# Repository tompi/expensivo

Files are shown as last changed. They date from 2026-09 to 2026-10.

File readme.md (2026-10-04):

Expensivo
=========

A wireless version of the [Cheapino](https://github.com/tompi/cheapino): same
shape and key layout, but with a nice!nano in each half, ZMK and Bluetooth
between the halves. Not quite as cheap anymore, hence the name.

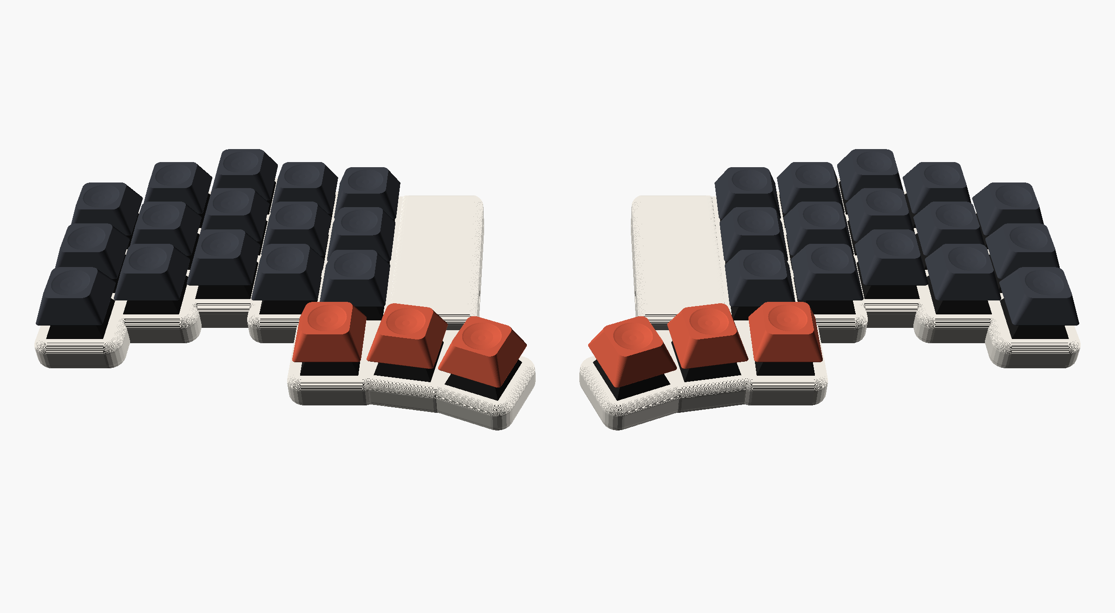
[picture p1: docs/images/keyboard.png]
Expensivo, both halves


- 36 keys (3x5 + 3 thumb keys per half), MX hotswap sockets
- every key has its own pin on the nice!nano: no diodes, no matrix
- one reversible PCB for both halves: the left half is built on the front,
  the right half on the back
- LiPo battery, power switch and reset button on each half
- optional EC11 encoder on the right half
- 3D-printed case with an optional magnetic cover over the nice!nano

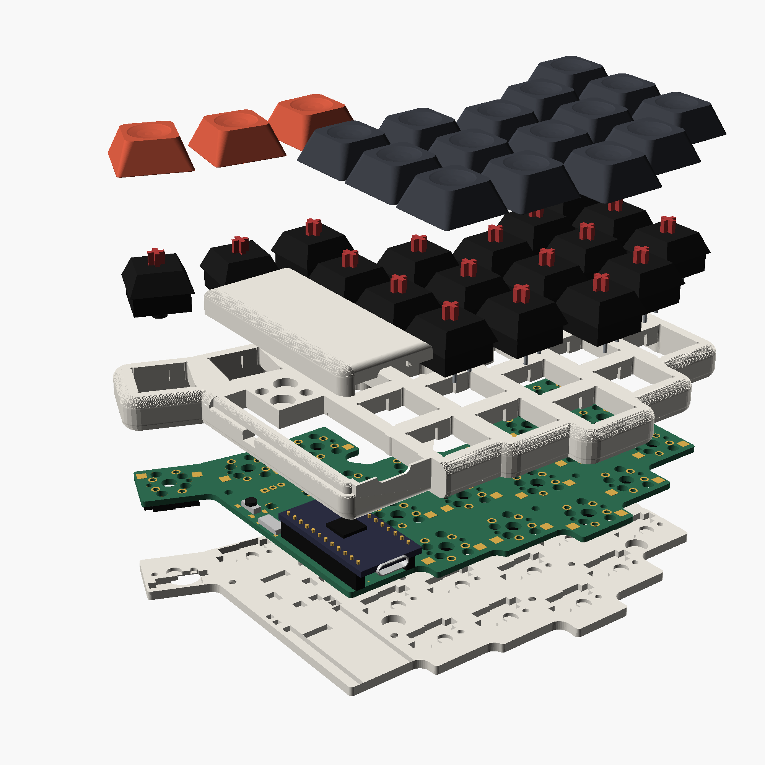
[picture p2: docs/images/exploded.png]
Exploded view: keycaps, switches, top case and cover, PCB with nice!nano, bottom plate


Parts per keyboard
------------------

| Part | Qty | Notes |
|---|----:|---|
| PCB | 2 | same board for both halves, see [Ordering the PCB](#ordering-the-pcb) |
| nice!nano v2 | 2 | or a compatible nRF52840 Pro Micro clone |
| Sockets + pins for the nice!nano | 2 sets | 12-pin single row; the case assumes the nano sits 4.9 mm above the PCB |
| LiPo battery | 2 | fits under the nano between the sockets, e.g. 301230 (3 x 12 x 30 mm); may stick out ~6 mm past the nano |
| MX switches | 36 | |
| Kailh MX hotswap sockets | 36 | MX, not low profile |
| Slide switch PCM12SMTR | 2 | one per half |
| Tactile switch TL3342 | 2 | reset, one per half |
| Keycaps | 36 | |
| EC11 encoder | 0-1 | optional, right half only |

For the case, per keyboard: 16 M2 heat-set inserts (4 mm long, 3 mm OD),
16 M2x5 countersunk screws, silicone bumpers (10 mm), 8 + 8 6x2 mm magnets
(8 in the bottom plates, 8 for the two covers).

Building it
-----------

The PCB is reversible, so it matters which side you solder on:

- **left half:** everything on the front side (the side marked LEFT);
  hotswap sockets on the back
- **right half:** everything on the back side (marked RIGHT); hotswap sockets on the front
- the nice!nano goes on the same side as its label, components facing up
- bridge the four solder jumpers next to the nano's top pins on the side the
  nano is on (marked "BRIDGE ALL 4"), and leave the other four open
- the power switch and reset button have a footprint on each side; fit only
  the one on top
- battery to the pads below the nano, + and - are marked

The [schematic](pcb/expensivo.kicad_sch) shows how it is wired, including
which nano pin ends up on which hole on each side.

Firmware
--------

ZMK, built by GitHub Actions on every push (see the Actions tab for the
`.uf2` files). The left half is the central and has ZMK Studio enabled.

- keymap: [config/expensivo.keymap](config/expensivo.keymap)
- shield: [zmk/boards/shields/expensivo](zmk/boards/shields/expensivo)

To flash, double-tap reset and copy the matching `.uf2` to the drive that
shows up. Flash `settings_reset` first if the nanos were used before.

Case
----

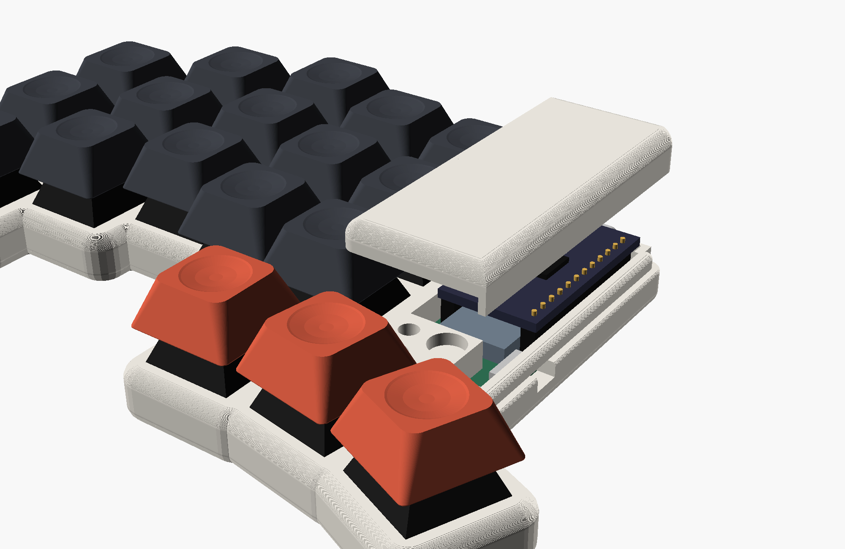
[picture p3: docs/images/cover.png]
Cover lifted off, showing the magnets and locating pegs


OpenSCAD files in [case/](case), see [case/readme.md](case/readme.md). The
top frames print top face down without supports, so do the covers; the
covers hold on with magnets and can be left off.

Ordering the PCB
----------------

`scripts/gerbers.sh` writes `build/expensivo-jlcpcb.zip`, ready for JLCPCB:
2 layers, 1.6 mm, default settings. 5 boards is two keyboards and a spare.
Choose ENIG if you want the copper logo to stay shiny.

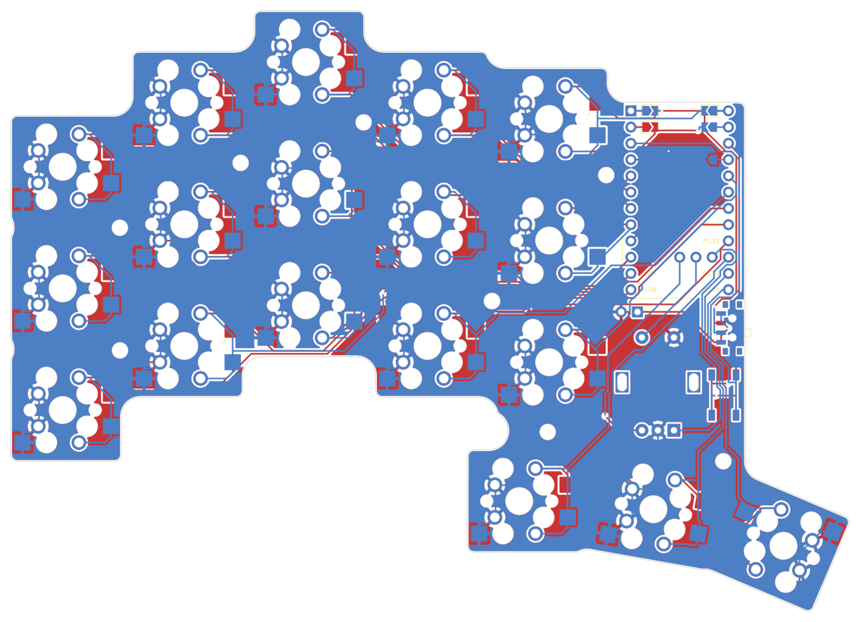
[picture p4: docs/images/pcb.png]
The PCB


How it's made
-------------

Everything is generated by scripts, so edit those rather than the outputs:

| Script | Makes |
|---|---|
| `scripts/build.sh` | the full board build: footprint, PCB, routing, DRC/ERC, schematic, case data |
| `scripts/build_pcb.py` | the PCB, starting from the Cheapino board: parts, nets, outline, logo |
| `scripts/gen_nano_footprint.py` | the reversible nice!nano footprint |
| `scripts/gen_schematic.py` | the schematic, from the PCB's parts and nets |
| `scripts/gen_zmk.py` | the ZMK shield pin lists |
| `scripts/gen_case.py` | PCB geometry for the OpenSCAD case |
| `scripts/gerbers.sh` | Gerbers and drill files for JLCPCB |

The pin map shared by the PCB, schematic and firmware is in
`scripts/layout.py`. Routing is done by Freerouting (downloaded on first run,
needs Java). The scripts expect KiCad 8 in `/Applications/KiCad`.

License
-------

This work is licensed under a [Creative Commons Attribution license.](LICENSE.txt)

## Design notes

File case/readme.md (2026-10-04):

3D-printed case
===============

Adapted from the cheapino case (`../cheapino/case`). Parts:

- `expensivo-top-left.scad`, `expensivo-top-right.scad`: top frames, flat on top
  like the cheapino case and flipped for printing (top face on the bed). The
  nice!nano sits in an open well.
- `expensivo-cover-left.scad`, `expensivo-cover-right.scad`: optional covers over
  the nice!nano (on 4.9 mm sockets), also printed top face down. Under the
  cover everything is open from the pcb to its roof (10 mm), so the battery
  can stick out past the nano's end. Each cover holds on with two 6x2 mm
  magnets glued into matching pockets in cover and top frame (check the
  polarity before the glue sets) and is located by two pegs; magnets and pegs
  share a small solid block at the thumb end.
- `expensivo-assembly.scad`: both halves put together, for looking at (F5)
- `expensivo-bottom-left.scad`, `expensivo-bottom-right.scad`: bottom plates

All board geometry (outline, keys, holes, parts) comes from `expensivo-pcb.scad`,
which `scripts/gen_case.py` generates from the PCB (`scripts/build.sh` runs it),
so the case follows PCB changes. Positions typed in by hand (bumpers, magnets)
are in KiCad coordinates, see `at()` in `modules.scad`.

Compared to the cheapino case: no RJ45 or diode cutouts; both halves get a
nice!nano well, a snug USB-C opening in a flat end face (lower half in the top
frame, upper half in the cover), a slot for the power switch lever and
room for the reset button (take the cover off to press it). The battery sits under the nice!nano,
between the socket rows, and may stick out about 6 mm past its end. The nano's stack (socket height, parts, mid-mount USB-C position and size,
clearances) is set in the "cover over the nice!nano" part of `modules.scad`.
To fit the encoder after all, pass `encoder=true` in `expensivo-top-right.scad`;
the cover's magnets use that spot, so that half then goes without a cover.

Render with a recent OpenSCAD snapshot with the manifold backend enabled, e.g.

    openscad --enable=manifold -o top-left.stl expensivo-top-left.scad

The USB-C numbers are measured on the nice!nano v2 model and match the common
33 x 17.78 mm clones; check them against your board (height of the shell
above the PCB, and how far it sticks out past the nano's edge) before printing.
The end wall beside the port is only as thick as that overhang (0.74 mm).

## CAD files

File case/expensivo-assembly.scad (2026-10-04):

// Visual assembly of both halves: case, pcb, nice!nano, switches and keycaps.
// For looking at only (F5); the case parts are imported from the STLs in
// build/case (in print orientation), so render those parts to STL first.
// explode > 0 spreads the layers apart vertically to show what is inside.
$fn = 34;
step = 0.5;
include <modules.scad>

explode = 0;
show_top = true;      // false to see inside
show_cover = true;
cover_lift = 0;       // lift the cover off to show the magnets and pegs
show_caps = true;
show_right = true;
half_gap = 150;       // distance between the two halves' centres

pcb_color = "#2d6a4f";
copper_color = "#d4a84b";
case_color = "#e9e5dc";
cover_color = "#e9e5dc";
cap_color = "#3a3d44";
cap_accent = "#c8553d";

// height of each layer when exploded
function lift(layer) = explode * layer;
L_PCB = 1;      // pcb, sockets, nano
L_TOP = 2;      // top frame
L_SWITCH = 3;   // switches
L_COVER = 3;    // cover (beside the switches)
L_CAP = 4;      // keycaps

module pcb_pad_shape(p) {
    translate([p[0], p[1]]) rotate(p[4])
        if (p[5] == 1) resize([p[2], p[3]]) circle(d=1);
        else square([p[2], p[3]], center=true);
}

// board with its drill holes, and the copper pads on the top side
module pcb() {
    translate([0, 0, bottom_plate_thickness]) {
        color(pcb_color) linear_extrude(pcb_thickness) difference() {
            base();
            for (p = pads_front) if (p[6] > 0) translate([p[0], p[1]]) circle(d=p[6]);
        }
        color(copper_color) translate([0, 0, pcb_thickness]) linear_extrude(0.05)
            difference() {
                for (p = pads_front) pcb_pad_shape(p);
                for (p = pads_front) if (p[6] > 0) translate([p[0], p[1]]) circle(d=p[6]);
            }
    }
}

// hotswap sockets under the board (the left half has them on the back)
module sockets(bottom) {
    color("#1b1b1b")
    for (k = keys)
        translate([k[0], k[1], bottom_plate_thickness - 1.85]) rotate(k[2]) translate([0.57, 4.7, 0])
            translate([0, bottom ? -9.42 : 0, 0]) mirror([0, bottom ? 0 : 1, 0])
                linear_extrude(1.85) projection() hotswap_mx();
}

// Cherry MX style switch, its bottom resting on the pcb
module mx_switch() {
    color("#9aa0a6") for (p = [[-3.81, 2.54], [2.54, 5.08]]) translate([p[0], p[1], top_of_pcb - 3.3])
        cylinder(h=3.3, d=1);
    color("#1b1b1b") translate([0, 0, top_of_pcb - 3.3]) cylinder(h=3.3, d=3.8);
    color("#1b1b1b") translate([0, 0, top_of_pcb])
        linear_extrude(case_top - top_of_pcb) square(14, center=true);
    color("#1b1b1b") hull() {
        translate([0, 0, case_top]) linear_extrude(0.1) square(15.6, center=true);
        translate([0, 0, case_top + 5.2]) linear_extrude(0.1) square(11, center=true);
    }
    color("#b33a3a") translate([0, 0, case_top + 5.2]) linear_extrude(3.4) {
        square([4, 1.2], center=true);
        square([1.2, 4], center=true);
    }
}

// DSA-like keycap: straight tapered sides and a slightly dished top.
module keycap(accent=false) {
    color(accent ? cap_accent : cap_color) difference() {
        hull() {
            linear_extrude(0.1) offset(r=1) square(18.2 - 2, center=true);
            translate([0, 0, 7.4]) linear_extrude(0.1) offset(r=2) square(12.7 - 4, center=true);
        }
        translate([0, 0, 7.4 + 20 - 0.6]) sphere(r=20, $fn=64);
    }
}

// nice!nano on its sockets, with the battery between the socket rows
module mcu() {
    nano_w = nano[2] - nano[0];
    nano_l = nano[3] - nano[1];
    pin_x = [nano[0] + 1.62, nano[2] - 1.62];
    // sockets
    color("#111111") for (x = pin_x)
        translate([x - 1.27, nano[1] + 0.4, top_of_pcb]) cube([2.54, 30.5, socket_height]);
    // battery
    // sticking out past the nano's end, into the space under the cover
    color("#6c7a89") translate([nano_x - 6, nano[1] - 4, top_of_pcb]) cube([12, 30, 3]);
    translate([0, 0, top_of_pcb + socket_height]) {
        color("#2b2d42") translate([nano[0], nano[1], 0]) cube([nano_w, nano_l, nano_thickness]);
        // pins through the nano
        color(copper_color) for (x = pin_x, i = [0:11])
            translate([x, nano[3] - 3.2 - i * 2.54, 0]) cylinder(h=nano_thickness + 0.8, d=0.8);
        // controller
        color("#111111") translate([nano_x - 3.5, nano[1] + 12, nano_thickness]) cube([7, 7, 0.9]);
    }
    // mid-mount USB-C receptacle, through the nano's board
    color("#c0c0c0") difference() {
        translate([nano_x, usb_mouth - usb_depth, usb_zc]) rotate([-90, 0, 0]) linear_extrude(usb_depth)
            hull() for (dx = [-1, 1]) translate([dx * (usb_width - usb_height) / 2, 0]) circle(d=usb_height);
        translate([nano_x, usb_mouth - 6.5, usb_zc]) rotate([-90, 0, 0]) linear_extrude(7)
            hull() for (dx = [-1, 1]) translate([dx * (usb_width - usb_height) / 2, 0]) circle(d=usb_height - 0.6);
    }
}

// small parts on the pcb: power switch, reset button
module small_parts() {
    color("#c0c0c0") translate([0, 0, top_of_pcb]) box(power_switch, 1.4, -0.4);
    color("#c0c0c0") translate([0, 0, top_of_pcb]) box(reset_button, 1.5, -1.3);
    color("#1b1b1b") translate([(reset_button[0] + reset_button[2]) / 2,
                               (reset_button[1] + reset_button[3]) / 2, top_of_pcb + 1.5])
        cylinder(h=1, d=3);
}

module switches_and_caps() {
    for (k = keys) translate([k[0], k[1], 0]) rotate(k[2]) {
        translate([0, 0, lift(L_SWITCH) - lift(L_PCB)]) mx_switch();
        if (show_caps) translate([0, 0, case_top + 6.3 + lift(L_CAP) - lift(L_PCB)])
            keycap(accent = k[1] < -25);   // thumb keys in the accent colour
    }
}

// the insides of one half, in the front view frame
module insides(left) {
    translate([0, 0, lift(L_PCB)]) {
        pcb();
        sockets(left);
        mcu();
        small_parts();
        switches_and_caps();
    }
}

// bottom plate, top case and cover from their STLs; the bottom plate is printed
// the way it sits, the others are turned back from their print orientation
module top_parts(side) {
    color(case_color) import(str("../build/case/expensivo-bottom-", side, ".stl"));
    if (show_top) color(case_color) translate([0, 0, lift(L_TOP)])
        rotate([0, 180, 0]) translate([0, 0, -case_top])
            import(str("../build/case/expensivo-top-", side, ".stl"));
    if (show_top && show_cover) color(cover_color) translate([0, 0, lift(L_COVER) + cover_lift])
        rotate([0, 180, 0]) translate([0, 0, -hump_top])
            import(str("../build/case/expensivo-cover-", side, ".stl"));
}

translate([-half_gap / 2, 0, 0]) {
    insides(true);
    top_parts("left");
}

// the right half is the same pcb flipped; its case STLs are already mirrored
if (show_right) translate([half_gap / 2, 0, 0]) {
    mirror([1, 0, 0]) insides(false);
    top_parts("right");
}

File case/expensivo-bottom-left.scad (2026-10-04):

// hotswap socket is ~1.75 high at the highest.
$fn = $preview ? 10 : 96;
include <modules.scad>

// silicone bumpers and magnets, in KiCad coordinates (front view). All clear the board
// edge and pin pockets; magnets also clear the socket pockets. Bumper recesses may
// touch socket pockets (as on the cheapino), the bumper pad covers that.
bumpers = [[164.86, 72.05], [164.61, 118.8], [179.11, 129.3], [140.61, 118.9],
           [104.31, 51.95], [102.36, 86.1], [66.86, 102.5], [66.86, 68.3]];
magnets = [[150.36, 76.55], [150.86, 112.05], [76.61, 66.25], [83.36, 93.5]];

// Rotate so you dont need to do that in extruder
translate([0,0,2.5])
rotate([0,180,0])
mirror([1,0,0])
difference() {
    bottom();
    switches(true);
    tht_pockets();
    mounting_holes();
    for (b = bumpers) at(b) bumper();
    for (m = magnets) at(m) magnet();
}

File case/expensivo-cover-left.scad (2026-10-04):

// Optional cover over the nice!nano; holds on with two 6x2 mm magnets,
// glued into the cover and the top case (mind the polarity).
step = 0.04;
$fn = $preview ? 10 : 96;
include <modules.scad>

// Printed upside down, top face on the bed
translate([0,0,hump_top])
rotate([0,180,0])
cover();

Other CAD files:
case/expensivo-bottom-right.scad
case/expensivo-cover-right.scad
case/expensivo-pcb.scad
case/expensivo-top-left.scad
case/expensivo-top-right.scad
case/modules.scad

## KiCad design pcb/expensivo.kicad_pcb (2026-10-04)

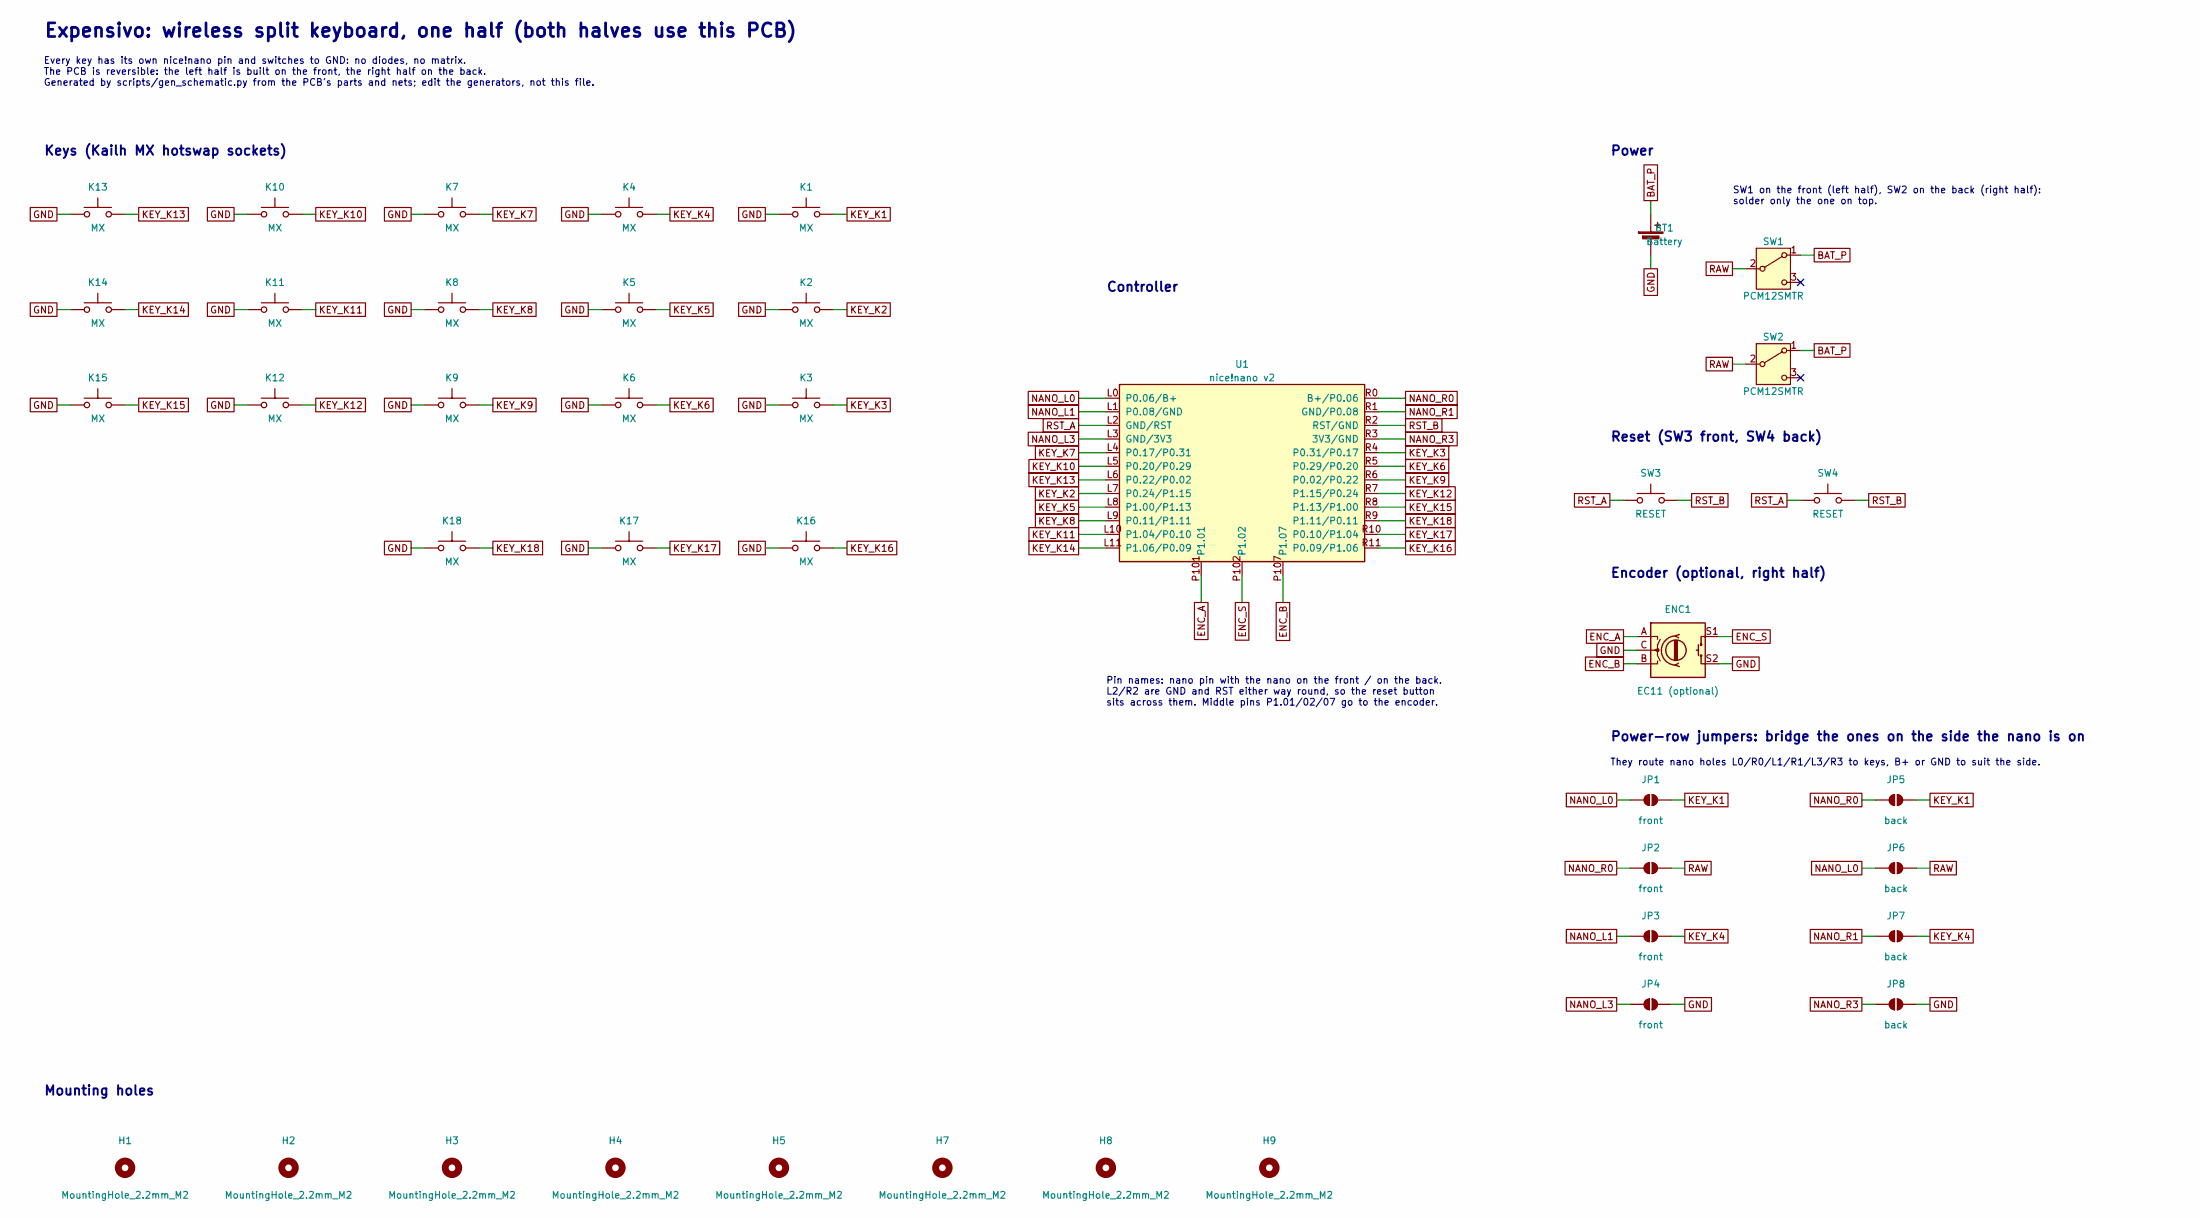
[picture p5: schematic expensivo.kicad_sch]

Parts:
BT1: Battery; PinHeader_1x02_P2.54mm_Vertical
ENC1: EC11 (optional); RotaryEncoder_Alps_EC11E-Switch_Vertical_H20mm
H1, H2, H3, H4, H5, H7, H8, H9: MountingHole_2.2mm_M2
JP1, JP2, JP3, JP4: front; SolderJumper-2_P1.3mm_Open_TrianglePad1.0x1.5mm
JP5, JP6, JP7, JP8: back; SolderJumper-2_P1.3mm_Open_TrianglePad1.0x1.5mm
K1, K2, K3, K4, K5, K6, K7, K8, K9, K10, K11, K12, K13, K14, K15, K16, K17, K18: MX; Kailh_socket_MX_optional_reversible
SW1, SW2: PCM12SMTR; SW_SPDT_PCM12
SW3, SW4: RESET; SW_SPST_TL3342
U1: nice!nano v2; nice_nano_reversible

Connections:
BAT_P: BT1.1 (+), SW1.1 (A), SW2.1 (A)
ENC_A: ENC1.A, U1.P101 (P1.01)
ENC_B: ENC1.B, U1.P107 (P1.07)
ENC_S: ENC1.S1, U1.P102 (P1.02)
GND: BT1.2 (-), ENC1.C, ENC1.S2, JP4.2 (B), JP8.2 (B), K1.1, K2.1, K3.1, K4.1, K5.1, K6.1, K7.1, K8.1, K9.1, K10.1, K11.1, K12.1, K13.1, K14.1, K15.1, K16.1, K17.1, K18.1
KEY_K1: JP1.2 (B), JP5.2 (B), K1.2
KEY_K2: K2.2, U1.L7 (P0.24/P1.15)
KEY_K3: K3.2, U1.R4 (P0.31/P0.17)
KEY_K4: JP3.2 (B), JP7.2 (B), K4.2
KEY_K5: K5.2, U1.L8 (P1.00/P1.13)
KEY_K6: K6.2, U1.R5 (P0.29/P0.20)
KEY_K7: K7.2, U1.L4 (P0.17/P0.31)
KEY_K8: K8.2, U1.L9 (P0.11/P1.11)
KEY_K9: K9.2, U1.R6 (P0.02/P0.22)
KEY_K10: K10.2, U1.L5 (P0.20/P0.29)
KEY_K11: K11.2, U1.L10 (P1.04/P0.10)
KEY_K12: K12.2, U1.R7 (P1.15/P0.24)
KEY_K13: K13.2, U1.L6 (P0.22/P0.02)
KEY_K14: K14.2, U1.L11 (P1.06/P0.09)
KEY_K15: K15.2, U1.R8 (P1.13/P1.00)
KEY_K16: K16.2, U1.R11 (P0.09/P1.06)
KEY_K17: K17.2, U1.R10 (P0.10/P1.04)
KEY_K18: K18.2, U1.R9 (P1.11/P0.11)
NANO_L0: JP1.1 (A), JP6.1 (A), U1.L0 (P0.06/B+)
NANO_L1: JP3.1 (A), U1.L1 (P0.08/GND)
NANO_L3: JP4.1 (A), U1.L3 (GND/3V3)
NANO_R0: JP2.1 (A), JP5.1 (A), U1.R0 (B+/P0.06)
NANO_R1: JP7.1 (A), U1.R1 (GND/P0.08)
NANO_R3: JP8.1 (A), U1.R3 (3V3/GND)
RAW: JP2.2 (B), JP6.2 (B), SW1.2 (B), SW2.2 (B)
RST_A: SW3.1, SW4.1, U1.L2 (GND/RST)
RST_B: SW3.2, SW4.2, U1.R2 (RST/GND)

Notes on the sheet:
Expensivo: wireless split keyboard, one half (both halves use this PCB)
Every key has its own nice!nano pin and switches to GND: no diodes, no matrix. The PCB is reversible: the left half is built on the front, the right half on the back. Generated by scripts/gen_schematic.py from the PCB's parts and nets; edit the generators, not this file.
Keys (Kailh MX hotswap sockets)
Controller
Pin names: nano pin with the nano on the front / on the back. L2/R2 are GND and RST either way round, so the reset button sits across them. Middle pins P1.01/02/07 go to the encoder.
Power
SW1 on the front (left half), SW2 on the back (right half): solder only the one on top.
Reset (SW3 front, SW4 back)
Encoder (optional, right half)
Power-row jumpers: bridge the ones on the side the nano is on
They route nano holes L0/R0/L1/R1/L3/R3 to keys, B+ or GND to suit the side.
Mounting holes

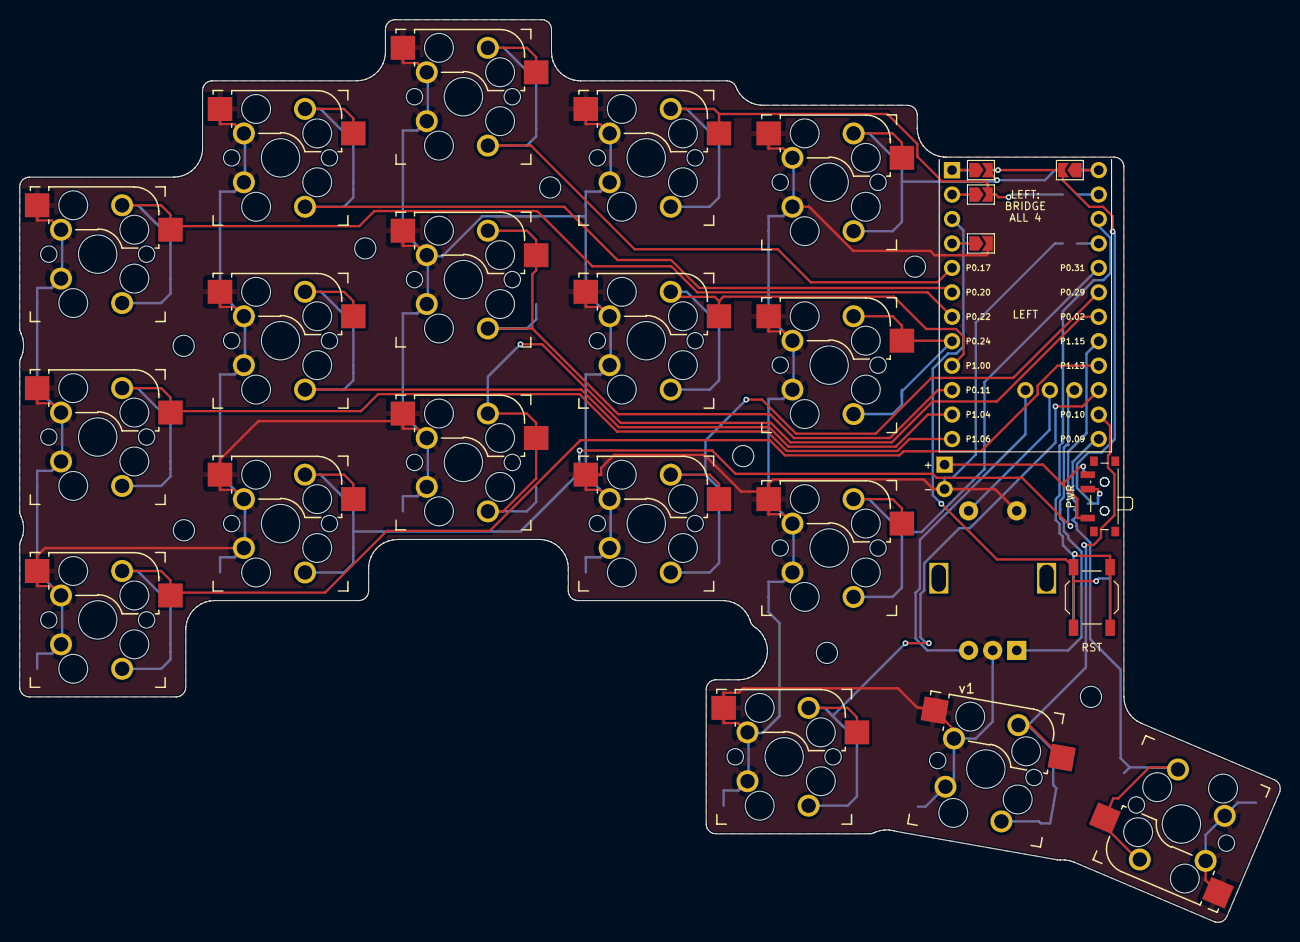
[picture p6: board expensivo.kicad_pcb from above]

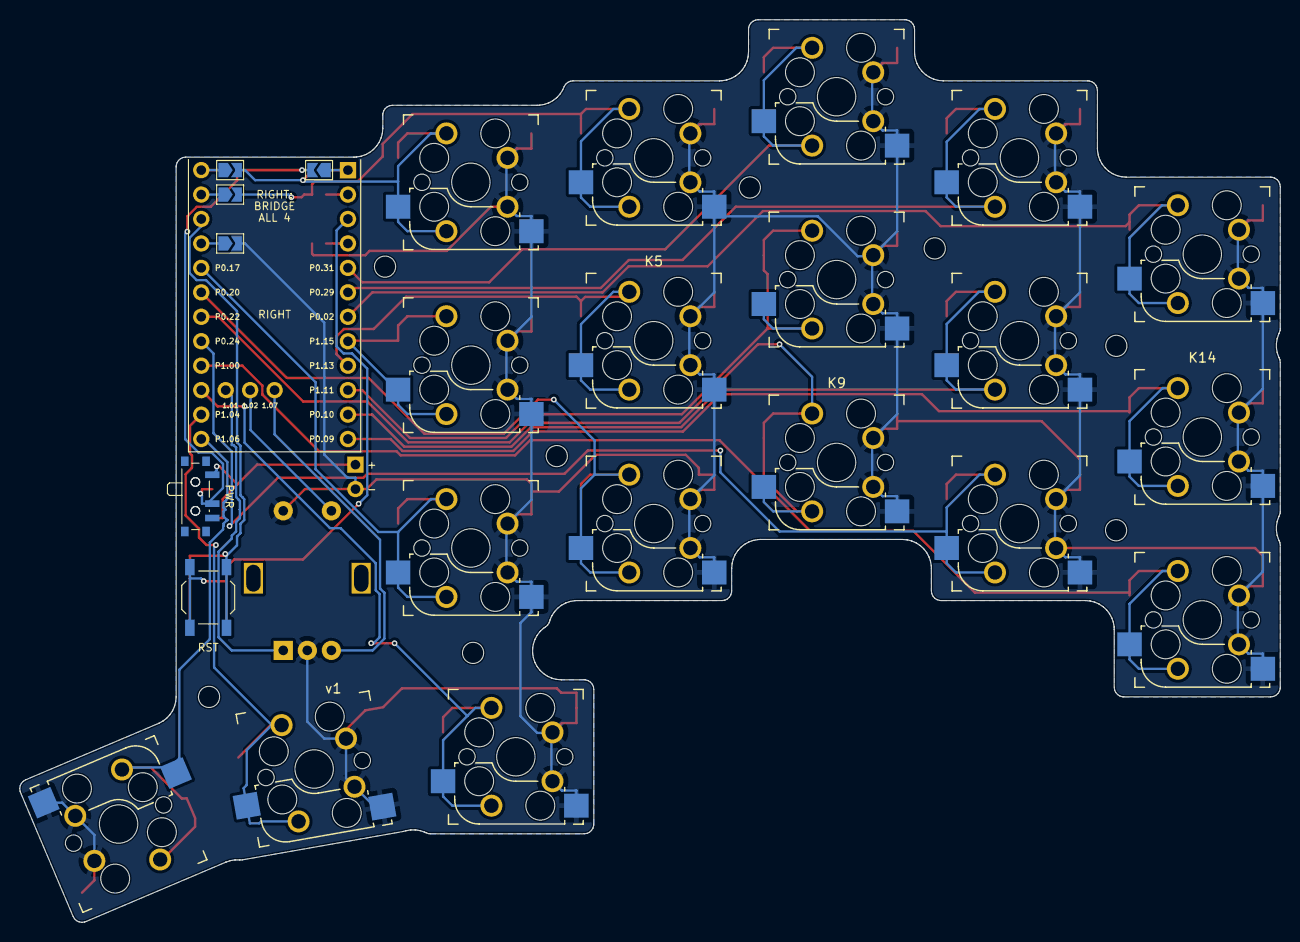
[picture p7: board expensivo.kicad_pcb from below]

Board: 2 copper layers, 131.0 x 93.8 mm, 41 parts (7 on the bottom side), 32 nets.

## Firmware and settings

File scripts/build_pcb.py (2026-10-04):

#!/usr/bin/env python3
"""Build the (unrouted) expensivo PCB from the cheapino outline.

Run with KiCad's bundled python:
  /Applications/KiCad/KiCad.app/Contents/Frameworks/Python.framework/Versions/3.9/bin/python3 scripts/build_pcb.py

Keeps from cheapino: board outline, switch footprints, mounting holes.
Removes: diodes, RJ45s, duplex jumpers, RP2040-Zero, all copper.
Adds: reversible nice!nano, battery pads, power switch, reset button,
optional EC11 encoder (right half), power-row jumpers.

The PCB is drawn as the LEFT half seen from the front (F). The right half
is the same PCB flipped, so everything for the right half lives on B.
"""
import json
import math
import os
import pcbnew

from layout import HOLE_TO_KEY, KEY_ROWS, THUMBS, symbol_uuid

HERE = os.path.dirname(os.path.abspath(__file__))
ROOT = os.path.normpath(os.path.join(HERE, ".."))
CHEAPINO = os.path.normpath(os.path.join(ROOT, "..", "cheapino", "pcb", "cheapino.kicad_pcb"))
OUT = os.path.join(ROOT, "pcb", "expensivo.kicad_pcb")
LIB = os.path.join(ROOT, "lib", "expensivo.pretty")
KLIB = "/Applications/KiCad/KiCad.app/Contents/SharedSupport/footprints/"

mm = pcbnew.FromMM

# --- placement ------------------------------------------------------------
NANO = (165.4, 74.3)            # footprint centre, USB towards the top edge
ROW_Y = [NANO[1] - 12.7 + 2.54 * i for i in range(12)]
XL, XR = NANO[0] - 7.62, NANO[0] + 7.62
JP_XL, JP_XR = XL + 3.0, XR - 3.0
ENC = (162.0, 104.0)            # encoder shaft, back side
PWR = (173.3, 95.5)             # side-actuated slide switch at the right edge
RST = (172.3, 106.0)            # reset button
# battery + / -, one above the other beside the nano's end, clear of the battery
# sliding in under the nano (between the socket rows, from x 159.4)
BAT = [(157.0, 92.2), (157.0, 94.74)]
LOGO = (162.4, 108.1)           # between the encoder's mounting tabs and its A/B/C pins
LOGO_SIZE = 2.5
BYLINE = (164.6, 115.4)
VERSION = "v1"
VERSION_AT = (159.3, 115.45)    # left of the byline

# --- outline --------------------------------------------------------------
# board around each key centre (left, top, right, bottom); +x is the socket pad side
# just clears the hotswap socket bodies, so the edge hides ~1 mm under the keycaps
KEY_BOX = (-8.1, -8.0, 9.15, 8.0)
KEY_BOX_EXTRA = {}  # per-key (left, top, right, bottom) additions to KEY_BOX
# turned 180 degrees so the socket pads face inwards and the edge can hug the outer side
FLIPPED_KEYS = ("K16",)
BODY_MARGIN = 0.5  # board around part bodies
HOLE_R = 2.5      # board around each mounting hole
PAD_EDGE = 0.3    # minimum pad to board edge distance
FILL_R = 3.0      # gaps narrower than 2x this between keys/parts get filled
ROUND_R = 1.0     # outside corner radius


def load(lib, name):
    fp = pcbnew.FootprintLoad(lib, name)
    assert fp, (lib, name)
    # library nickname as in the global footprint table, so the schematic can name it
    fp.SetFPID(pcbnew.LIB_ID(os.path.basename(lib.rstrip("/")).replace(".pretty", ""), name))
    return fp


def place(board, fp, ref, xy, rot=0.0, back=False, value=None):
    fp.SetReference(ref)
    if value:
        fp.SetValue(value)
    board.Add(fp)
    pos = pcbnew.VECTOR2I(mm(xy[0]), mm(xy[1]))
    fp.SetPosition(pos)
    if back:
        fp.Flip(pos, True)
    fp.SetOrientationDegrees(rot)
    fp.Reference().SetVisible(False)  # no room; silkscreen labels are added separately
    return fp


def pad_xy(p):
    q = p.GetPosition()
    return (pcbnew.ToMM(q.x), pcbnew.ToMM(q.y))


def poly(points):
    s = pcbnew.SHAPE_POLY_SET()
    s.NewOutline()
    for x, y in points:
        s.Append(mm(x), mm(y))
    return s


def trim_outline(board):
    """Replace the cheapino outline with the smallest one covering the keycaps and parts."""
    shapes = pcbnew.SHAPE_POLY_SET()

    def add(s):
        shapes.BooleanAdd(s, pcbnew.SHAPE_POLY_SET.PM_FAST)

    pads = pcbnew.SHAPE_POLY_SET()
    boxes, holes = {}, []
    for fp in board.GetFootprints():
        ref = fp.GetReference()
        x, y = pcbnew.ToMM(fp.GetPosition().x), pcbnew.ToMM(fp.GetPosition().y)
        if ref.startswith("K"):
            l, t, r, b = (a + e for a, e in zip(KEY_BOX, KEY_BOX_EXTRA.get(ref, (0, 0, 0, 0))))
            s = poly([(x + l, y + t), (x + r, y + t), (x + r, y + b), (x + l, y + b)])
            s.Rotate(fp.GetOrientation(), fp.GetPosition())
            add(s)
        elif ref.startswith("H"):
            holes.append((x, y))
            add(poly([(x + HOLE_R * math.cos(a * math.pi / 16), y + HOLE_R * math.sin(a * math.pi / 16))
                      for a in range(32)]))
        else:
            bb = pcbnew.BOX2I()
            if ref in ("SW1", "SW2", "U1"):
                # the slide switch lever and the nano's USB end stick out past the edge,
                # so only cover their pads
                for p in fp.Pads():
                    bb.Merge(p.GetBoundingBox())
            else:
                # part body from its fab-layer drawing
                fab = pcbnew.B_Fab if fp.IsFlipped() else pcbnew.F_Fab
                for g in fp.GraphicalItems():
                    if g.GetLayer() == fab and isinstance(g, pcbnew.PCB_SHAPE):  # not the ref text
                        bb.Merge(g.GetBoundingBox())
            bb.Inflate(mm(BODY_MARGIN))
            boxes[ref] = bb
            if bb.GetWidth():
                add(poly([(pcbnew.ToMM(bb.GetLeft()), pcbnew.ToMM(bb.GetTop())),
                          (pcbnew.ToMM(bb.GetRight()), pcbnew.ToMM(bb.GetTop())),
                          (pcbnew.ToMM(bb.GetRight()), pcbnew.ToMM(bb.GetBottom())),
                          (pcbnew.ToMM(bb.GetLeft()), pcbnew.ToMM(bb.GetBottom()))]))
        for p in fp.Pads():
            p.TransformShapeToPolygon(pads, p.GetPrincipalLayer(), mm(PAD_EDGE), mm(0.01))
    # straight right edge from the nano's top corner down to the rightmost mounting hole
    right = max(pcbnew.ToMM(boxes[r].GetRight()) for r in ("U1", "SW1", "SW3"))
    hole_y = max(holes)[1]
    add(poly([(NANO[0], pcbnew.ToMM(boxes["U1"].GetTop())), (right, pcbnew.ToMM(boxes["U1"].GetTop())),
              (right, hole_y), (NANO[0], hole_y)]))

    corner = pcbnew.CORNER_STRATEGY_ROUND_ALL_CORNERS
    # close the gaps between keys and parts, then round the outside corners
    shapes.Inflate(mm(FILL_R), corner, mm(0.01))
    shapes.Deflate(mm(FILL_R), corner, mm(0.01))
    shapes.Deflate(mm(ROUND_R), corner, mm(0.01))
    shapes.Inflate(mm(ROUND_R), corner, mm(0.01))
    shapes.BooleanAdd(pads, pcbnew.SHAPE_POLY_SET.PM_FAST)
    assert shapes.OutlineCount() == 1, f"outline split into {shapes.OutlineCount()} pieces"

    outline = pcbnew.SHAPE_POLY_SET()
    outline.AddOutline(shapes.Outline(0))  # drop any enclosed holes
    old = [d for d in board.GetDrawings() if d.GetLayerName() == "Edge.Cuts"]
    for d in old:
        board.Remove(d)
    edge = pcbnew.PCB_SHAPE(board, pcbnew.SHAPE_T_POLY)
    edge.SetPolyShape(outline)
    edge.SetLayer(pcbnew.Edge_Cuts)
    edge.SetWidth(mm(0.1))
    edge.SetFilled(False)
    board.Add(edge)
    return old  # keep the removed items alive, see main()


def main():
    board = pcbnew.LoadBoard(CHEAPINO)

    # strip copper, zones and old parts
    # removed items are kept referenced: letting SWIG destroy them mid-run
    # corrupts the board's item lists
    removed = [board.GetArea(i) for i in range(board.GetAreaCount())]
    removed += list(board.GetTracks())
    # the logo and byline are solder mask openings showing the copper pour; keep them
    def is_logo(d):
        return isinstance(d, pcbnew.PCB_TEXT) and d.GetLayerName() in ("F.Mask", "B.Mask")
    removed += [d for d in board.GetDrawings() if d.GetLayerName() != "Edge.Cuts" and not is_logo(d)]
    keep = ("Kailh_socket_MX_optional_reversible", "MountingHole")
    removed += [fp for fp in board.GetFootprints() if not any(k in fp.GetFPIDAsString() for k in keep)]
    for item in removed:
        board.Remove(item)

    nets = {}

    def net(name):
        if name not in nets:
            n = pcbnew.NETINFO_ITEM(board, name)
            board.Add(n)
            nets[name] = n
        return nets[name]

    # drop every old net by clearing pads, then re-add our own
    for fp in board.GetFootprints():
        for p in fp.Pads():
            p.SetNetCode(0)

    key_net = {k: f"KEY_{k}" for k in HOLE_TO_KEY.values()}

    # switches: pad 1 -> GND, pad 2 -> key net
    # the keys come from the cheapino board; give them our library footprint's 3D models
    key_lib = load(LIB, "Kailh_socket_MX_optional_reversible")
    hole_count = 0
    for fp in board.GetFootprints():
        ref = fp.GetReference()
        if ref.startswith("K"):
            fp.SetValue("MX")
            fp.Models().clear()
            for m in key_lib.Models():
                fp.Models().push_back(m)
            fp.SetFPID(pcbnew.LIB_ID("expensivo", "Kailh_socket_MX_optional_reversible"))
            fp.SetAttributes(pcbnew.FP_THROUGH_HOLE)
            if ref in FLIPPED_KEYS:
                fp.SetOrientationDegrees(fp.GetOrientationDegrees() + 180)
            for p in fp.Pads():
                if p.GetNumber() == "1":
                    p.SetNet(net("GND"))
                elif p.GetNumber() == "2":
                    p.SetNet(net(key_net[ref]))
        if ref == "REF**":
            # unique refs are required for the Specctra export
            hole_count += 1
            fp.SetReference(f"H{hole_count}")

    # drop the bottom mounting hole between the thumbs so the outline can hug the keys there
    holes_fp = [fp for fp in board.GetFootprints() if fp.GetReference().startswith("H")]
    bottom = max(holes_fp, key=lambda fp: fp.GetPosition().y)
    board.Remove(bottom)
    removed.append(bottom)

    # nice!nano
    nano = place(board, load(LIB, "nice_nano_reversible"), "U1", NANO, value="nice!nano v2")
    nano.SetFPID(pcbnew.LIB_ID("expensivo", "nice_nano_reversible"))
    holes = {}
    for i in range(12):
        holes[f"L{i}"] = f"NANO_L{i}" if i < 4 else key_net.get(HOLE_TO_KEY.get(f"L{i}"))
        holes[f"R{i}"] = f"NANO_R{i}" if i < 4 else key_net.get(HOLE_TO_KEY.get(f"R{i}"))
    holes["L2"], holes["R2"] = "RST_A", "RST_B"
    holes["P101"], holes["P102"], holes["P107"] = "ENC_A", "ENC_S", "ENC_B"
    for p in nano.Pads():
        p.SetNet(net(holes[p.GetNumber()]))

    # power-row jumpers: bridge the ones on the same side as the nano
    jlib, jname = KLIB + "Jumper.pretty", "SolderJumper-2_P1.3mm_Open_TrianglePad1.0x1.5mm"
    jumpers = [
        # ref, side, hole, x, row, other net
        ("JP1", "F", "L0", JP_XL, 0, key_net[HOLE_TO_KEY["KA"]]),
        ("JP2", "F", "R0", JP_XR, 0, "RAW"),
        ("JP3", "F", "L1", JP_XL, 1, key_net[HOLE_TO_KEY["KB"]]),
        ("JP4", "F", "L3", JP_XL, 3, "GND"),
        ("JP5", "B", "R0", JP_XR, 0, key_net[HOLE_TO_KEY["KA"]]),
        ("JP6", "B", "L0", JP_XL, 0, "RAW"),
        ("JP7", "B", "R1", JP_XR, 1, key_net[HOLE_TO_KEY["KB"]]),
        ("JP8", "B", "R3", JP_XR, 3, "GND"),
    ]
    for ref, side, hole, x, row, other in jumpers:
        fp = place(board, load(jlib, jname), ref, (x, ROW_Y[row]), back=(side == "B"),
                   value="front" if side == "F" else "back")
        hx = XL if hole.startswith("L") else XR
        # pad nearest the hole gets the hole net; rotate so that pad faces the hole
        pads = sorted(fp.Pads(), key=lambda p: abs(pad_xy(p)[0] - hx))
        if pads[0].GetNumber() != "1":
            fp.SetOrientationDegrees(180)
            pads = sorted(fp.Pads(), key=lambda p: abs(pad_xy(p)[0] - hx))
        pads[0].SetNet(net(holes[hole]))
        pads[1].SetNet(net(other))

    # encoder, right half only (back side)
    enc = place(board, load(KLIB + "Rotary_Encoder.pretty", "RotaryEncoder_Alps_EC11E-Switch_Vertical_H20mm"),
                "ENC1", (0, 0), back=True, value="EC11 (optional)")
    enc.SetOrientationDegrees(90)
    # move so the shaft (pad-centroid of the MP tabs) sits at ENC
    mps = [pad_xy(p) for p in enc.Pads() if p.GetNumber() == "MP"]
    cx, cy = sum(p[0] for p in mps) / 2, sum(p[1] for p in mps) / 2
    enc.Move(pcbnew.VECTOR2I(mm(ENC[0] - cx), mm(ENC[1] - cy)))
    # its silkscreen outline would cross the copper logo; the pin layout already fixes the orientation
    for g in list(enc.GraphicalItems()):
        if g.GetLayer() == pcbnew.B_SilkS and isinstance(g, pcbnew.PCB_SHAPE):
            enc.Remove(g)
            removed.append(g)
    enc_nets = {"A": "ENC_A", "B": "ENC_B", "C": "GND", "S1": "ENC_S", "S2": "GND"}
    for p in enc.Pads():
        if p.GetNumber() in enc_nets:
            p.SetNet(net(enc_nets[p.GetNumber()]))

    # power switch on both sides, only one gets soldered
    for ref, back in (("SW1", False), ("SW2", True)):
        # actuator must point out of the right edge on both sides
        fp = place(board, load(KLIB + "Button_Switch_SMD.pretty", "SW_SPDT_PCM12"), ref, PWR,
                   rot=-90 if back else 90, back=back, value="PCM12SMTR")
        for p in fp.Pads():
            if p.GetNumber() == "1":
                p.SetNet(net("BAT_P"))
            elif p.GetNumber() == "2":
                p.SetNet(net("RAW"))
            elif p.GetNumber() == "3":
                # unused throw; named the way KiCad names a no-connect pin's net
                p.SetNet(net(f"unconnected-({ref}-C-Pad3)"))

    # reset button on both sides
    for ref, back in (("SW3", False), ("SW4", True)):
        fp = place(board, load(KLIB + "Button_Switch_SMD.pretty", "SW_SPST_TL3342"), ref, RST,
                   rot=90, back=back, value="RESET")
        for p in fp.Pads():
            p.SetNet(net("RST_A" if p.GetNumber() == "1" else "RST_B"))

    # battery pads (THT, usable from either side)
    batlib = KLIB + "Connector_PinHeader_2.54mm.pretty"
    bat = place(board, load(batlib, "PinHeader_1x02_P2.54mm_Vertical"), "BT1", BAT[0], rot=0,
                value="Battery")
    # wire pads, not a header: drop the header outline, it would run into the nano's
    for g in list(bat.GraphicalItems()):
        if g.GetLayer() in (pcbnew.F_SilkS, pcbnew.B_SilkS) and isinstance(g, pcbnew.PCB_SHAPE):
            bat.Remove(g)
            removed.append(g)
    for p in bat.Pads():
        p.SetNet(net("BAT_P" if p.GetNumber() == "1" else "GND"))
        want = BAT[0] if p.GetNumber() == "1" else BAT[1]
        assert all(abs(a - b) < 0.01 for a, b in zip(pad_xy(p), want)), (p.GetNumber(), pad_xy(p), want)

    removed += trim_outline(board)

    # silkscreen
    def text(s, xy, layer, size=1.0, rot=0):
        t = pcbnew.PCB_TEXT(board)
        t.SetText(s)
        t.SetPosition(pcbnew.VECTOR2I(mm(xy[0]), mm(xy[1])))
        t.SetLayer(board.GetLayerID(layer))
        t.SetTextSize(pcbnew.VECTOR2I(mm(size), mm(size)))
        t.SetTextThickness(mm(size * 0.15))
        t.SetTextAngleDegrees(rot)
        if layer.startswith("B."):
            t.SetMirrored(True)
        board.Add(t)

    # logo in the cheapino style: Impact text as bare copper, between the encoder pad rows
    for d in board.GetDrawings():
        if isinstance(d, pcbnew.PCB_TEXT) and d.GetLayerName() in ("F.Mask", "B.Mask"):
            if d.GetText().startswith("Cheapino"):
                d.SetText("Expensivo")
                d.SetTextSize(pcbnew.VECTOR2I(mm(LOGO_SIZE), mm(LOGO_SIZE)))
                xy = LOGO
            else:
                xy = BYLINE
            d.SetHorizJustify(pcbnew.GR_TEXT_H_ALIGN_CENTER)
            d.SetVertJustify(pcbnew.GR_TEXT_V_ALIGN_CENTER)
            d.SetPosition(pcbnew.VECTOR2I(mm(xy[0]), mm(xy[1])))
            # keep tracks out from under the exposed copper so the pour shows solid
            bb = d.GetEffectiveTextShape().BBox()
            bb.Inflate(mm(0.5))
            keepout = pcbnew.ZONE(board)
            keepout.SetIsRuleArea(True)
            keepout.SetDoNotAllowTracks(True)
            keepout.SetDoNotAllowVias(True)
            keepout.SetDoNotAllowCopperPour(False)
            keepout.SetDoNotAllowPads(False)
            keepout.SetDoNotAllowFootprints(False)
            keepout.SetLayer(pcbnew.F_Cu if d.GetLayerName() == "F.Mask" else pcbnew.B_Cu)
            keepout.Outline().NewOutline()
            for x, y in ((bb.GetLeft(), bb.GetTop()), (bb.GetRight(), bb.GetTop()),
                         (bb.GetRight(), bb.GetBottom()), (bb.GetLeft(), bb.GetBottom())):
                keepout.Outline().Append(x, y)
            board.Add(keepout)
    for side in ("F.SilkS", "B.SilkS"):
        text(VERSION, VERSION_AT, side, 1.0)
    board.GetTitleBlock().SetRevision(VERSION.lstrip("v"))
    text("LEFT", (NANO[0], 76.6), "F.SilkS", 0.8)
    text("RIGHT", (NANO[0], 76.6), "B.SilkS", 0.8)
    # between the jumper columns: which ones to bridge on this side
    for side, lines in (("F.SilkS", ("LEFT:", "BRIDGE", "ALL 4")), ("B.SilkS", ("RIGHT:", "BRIDGE", "ALL 4"))):
        for i, line in enumerate(lines):
            text(line, (NANO[0], ROW_Y[1] + 1.2 * i), side, 0.8)
    # - is left of + seen from the front, so the order flips on the back
    # left of the pads; the order is the same seen from either side
    for side in ("F.SilkS", "B.SilkS"):
        text("+", (BAT[0][0] - 1.7, BAT[0][1]), side, 0.8)
        text("-", (BAT[1][0] - 1.7, BAT[1][1]), side, 0.8)
    for side in ("F.SilkS", "B.SilkS"):
        text("RST", (RST[0], RST[1] + 5.2), side, 0.8)
        text("PWR", (PWR[0] - 3.2, PWR[1]), side, 0.8, rot=90)

    # design rules
    ds = board.GetDesignSettings()
    ds.m_TrackMinWidth = mm(0.2)
    ds.m_ViasMinSize = mm(0.6)
    ds.m_MinThroughDrill = mm(0.3)
    ds.m_CopperEdgeClearance = mm(0.2)
    ds.m_MinResolvedSpokes = 1
    ds.m_MinSilkTextHeight = mm(0.5)
    nc = ds.m_NetSettings.m_DefaultNetClass
    nc.SetClearance(mm(0.2))
    nc.SetTrackWidth(mm(0.25))
    nc.SetViaDiameter(mm(0.6))
    nc.SetViaDrill(mm(0.3))

    # link every footprint to its symbol in expensivo.kicad_sch (scripts/gen_schematic.py)
    for fp in board.GetFootprints():
        fp.SetPath(pcbnew.KIID_PATH("/" + symbol_uuid(fp.GetReference())))
        fp.SetSheetfile("expensivo.kicad_sch")
        fp.SetSheetname("")

    board.BuildListOfNets()
    board.SetFileName(OUT)
    pcbnew.SaveBoard(OUT, board)
    assert pcbnew.ExportSpecctraDSN(board, os.path.join(ROOT, "build", "expensivo.dsn")), "DSN export failed"

    # dump the pin mapping for the firmware generator
    mapping = {"holes": holes, "key_rows": KEY_ROWS, "thumbs": THUMBS, "hole_to_key": HOLE_TO_KEY}
    with open(os.path.join(ROOT, "build", "mapping.json"), "w") as f:
        json.dump(mapping, f, indent=2)

    for fp in board.GetFootprints():
        if fp.GetReference()[0] in "UJSEB":
            bb = fp.GetBoundingBox(False, False)
            print(fp.GetReference(), "B" if fp.IsFlipped() else "F",
                  [round(pcbnew.ToMM(v), 2) for v in (bb.GetLeft(), bb.GetTop(), bb.GetRight(), bb.GetBottom())],
                  [(p.GetNumber(), p.GetNetname(), tuple(round(c, 2) for c in pad_xy(p))) for p in fp.Pads() if p.GetNumber()][:8])
    print("saved", OUT)


if __name__ == "__main__":
    main()

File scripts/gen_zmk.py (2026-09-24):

#!/usr/bin/env python3
"""Generate the expensivo ZMK shield pin lists from the PCB hole mapping."""
import os

from layout import KEY_ROWS, THUMBS, key_pins

ROOT = os.path.normpath(os.path.join(os.path.dirname(os.path.abspath(__file__)), ".."))
SHIELD = os.path.join(ROOT, "zmk", "boards", "shields", "expensivo")

# encoder pins, only wired on the right half (nano on the back)
ENC_A, ENC_B, ENC_S = "P1.01", "P1.07", "P1.02"


def gpio(pin, flags="GPIO_ACTIVE_LOW | GPIO_PULL_UP"):
    port, num = pin[1:].split(".")
    return f"<&gpio{port} {int(num)} ({flags})>"


def key_order(right):
    """Keys in keymap order for one half: rows, then thumbs, left to right."""
    rows = [list(reversed(r)) if right else r for r in KEY_ROWS]
    thumbs = list(reversed(THUMBS)) if right else THUMBS
    return [k for r in rows for k in r] + thumbs


def overlay(right):
    pins = key_pins(back=right)
    keys = key_order(right)
    lines = [f"            {'= ' if i == 0 else ', '}{gpio(pins[k])} // {k}" for i, k in enumerate(keys)]
    if right:
        lines.append(f"            , {gpio(ENC_S)} // encoder push")
    out = ["// Generated by scripts/gen_zmk.py -- edit the generator, not this file.",
           '#include "expensivo.dtsi"', ""]
    if right:
        out += ["&default_transform {", "    col-offset = <18>;", "};", "",
                "&encoder {", "    status = \"okay\";", "};", ""]
    out += ["&kscan0 {", "    input-gpios", *lines, "            ;", "};", ""]
    return "\n".join(out)


def dtsi():
    rows = []
    for r in range(3):
        l = " ".join(f"RC(0,{r * 5 + c})" for c in range(5))
        rr = " ".join(f"RC(0,{18 + r * 5 + c})" for c in range(5))
        rows.append(f"            {l}    {rr}")
    rows.append("                            RC(0,15) RC(0,16) RC(0,17)    "
                "RC(0,33) RC(0,34) RC(0,35)   RC(0,36)")
    return f"""// Generated by scripts/gen_zmk.py -- edit the generator, not this file.
#include <dt-bindings/zmk/matrix_transform.h>
#include "expensivo-layout.dtsi"

// P0.09 / P0.10 are used as key inputs
&uicr {{
    nfct-pins-as-gpios;
}};

&expensivo_layout {{
    transform = <&default_transform>;
}};

/ {{
    chosen {{
        zmk,kscan = &kscan0;
        zmk,physical-layout = &expensivo_layout;
    }};

    default_transform: keymap_transform_0 {{
        compatible = "zmk,matrix-transform";
        columns = <37>;
        rows = <1>;
        // last entry is the (optional) encoder push on the right half
        map = <
{chr(10).join(rows)}
        >;
    }};

    kscan0: kscan {{
        compatible = "zmk,kscan-gpio-direct";
        wakeup-source;
    }};

    encoder: encoder {{
        compatible = "alps,ec11";
        a-gpios = {gpio(ENC_A, "GPIO_ACTIVE_HIGH | GPIO_PULL_UP")};
        b-gpios = {gpio(ENC_B, "GPIO_ACTIVE_HIGH | GPIO_PULL_UP")};
        steps = <80>;
        status = "disabled";
    }};

    sensors: sensors {{
        compatible = "zmk,keymap-sensors";
        sensors = <&encoder>;
        triggers-per-rotation = <20>;
    }};
}};
"""


def main():
    os.makedirs(SHIELD, exist_ok=True)
    files = {
        "expensivo.dtsi": dtsi(),
        "expensivo_left.overlay": overlay(False),
        "expensivo_right.overlay": overlay(True),
    }
    for name, text in files.items():
        with open(os.path.join(SHIELD, name), "w") as f:
            f.write(text)
        print("wrote", name)


if __name__ == "__main__":
    main()

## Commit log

2026-09-24 Add expensivo: wireless diodeless Cheapino-shaped split keyboard
    Reversible nice!nano PCB with direct-wired keys (no diodes), optional
    encoder on the right half via the nano's middle pins, and a ZMK config
    generated from the PCB pin mapping. scripts/build.sh regenerates,
    autoroutes and DRC-checks the board.
    [expensivo.kicad_pcb]
2026-09-26 Trim outline, add schematic and 3D-printed case
    PCB: outline generated to hug the keys (edge under the keycaps, straight
    along the nice!nano, bottom mounting hole dropped, outer thumb socket
    turned so its pads face inwards), Impact logo as exposed copper, nano USB
    end overhanging the edge.
    Schematic: generated from the PCB's parts and nets by
    scripts/gen_schematic.py; build.sh checks ERC and schematic parity.
    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
    [expensivo-assembly.scad, expensivo-bottom-left.scad, expensivo-bottom-right.scad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]
2026-09-26 Build for nice_nano//zmk; add JLCPCB gerber export
    ZMK main is on Zephyr 4.1, where the nice!nano v2 board is nice_nano//zmk.
    scripts/gerbers.sh checks DRC and schematic parity, then exports Gerbers
    and drill files with JLCPCB's settings to build/expensivo-jlcpcb.zip.
2026-09-26 Add readme with renders of the keyboard, case and PCB
2026-10-04 Move battery pads, label jumpers, add 3D models, v1, snug USB-C opening
    PCB: battery pads stacked beside the nano's corner, clear of the battery
    sliding in under the nano; "BRIDGE ALL 4" labels between the power-row
    jumpers on each side; "v1" silkscreen and board revision.
    3D: KiCad models for the hotswap sockets, MX switches and DSA keycaps
    (lib/expensivo.3dshapes, licenses in its README); the nice!nano model is
    downloaded by build.sh as it is CC BY-NC-SA.
    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
    [expensivo-assembly.scad, expensivo-pcb.scad, expensivo.kicad_pcb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]
2026-10-04 Case: cover skirt over the joint, rounded USB-end corner, no reset hole
    The cover gets a skirt along its outer side that reaches over the top
    frame's edge, so case and cover read as one wall; the frame steps in
    under it, with rounded edges for when the cover is off. The corner
    where the outer side meets the flat USB end is rounded again (3 mm),
    with the skirt and step nested about the same centre. The reset hole
    is gone: take the cover off to press reset. Parts render at $fn 96;
    renders refreshed.
    [expensivo-assembly.scad, expensivo-bottom-left.scad, expensivo-bottom-right.scad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]
2026-10-04 Assembly: show the real bottom plates, with their pockets
    The renders drew the bottom plate as a plain slab; import the rendered
    bottom-plate STLs instead, so the socket, pin and screw pockets show.
    [expensivo-assembly.scad]
2026-10-04 Bottom plate: one slot per nano pin row; exploded view from the USB side
    The nano's pin rows (and its three middle pins) get one long pocket each
    instead of a pocket per pin. The readme's exploded view now looks at the
    keyboard from behind, showing the USB port.
    [modules.scad]
2026-10-04 Case: straight wall from the inner thumb key up to the body
    The board outline has a small pocket between the inner thumb key and
    the keys above it; the case outline fills it, so the wall no longer
    steps in and out there. The PCB is unchanged.
    [modules.scad]
2026-10-21 CI: render the case STLs and commit them on every case change
2026-10-21 Case: regenerate STLs for 07a5c2e
2026-10-21 CI: upload the case STLs as an artifact instead of committing them
2026-10-21 Bottom plate: clear slivers between bumper recesses and socket pockets
2026-10-21 Case: render STLs through a checked full-precision export
2026-10-21 Case: install rtree for the STL checks
2026-10-22 ZMK: rename expensivo.conf to expensivo_left.conf so the left half uses it
    Zephyr only merges <shield>.conf, so mouse keys (CONFIG_ZMK_POINTING) and
    the battery proxy were never enabled in the left firmware.
2026-10-24 Case: lower the power switch lever slot, cut the board pocket from below
    The lever's slot now reaches 1 mm below the pcb's top face, so the lever
    isn't caught and bent while the board goes into the frame. The pocket for
    the pcb and bottom plate starts 1 mm below the case's bottom face, so the
    cut no longer leaves a stray skin there.
2026-10-24 Case: walls round from top to bottom
    The wall's rounding is now a quarter ellipse, edge_bulge wide and
    edge_radius high, with edge_radius at half the case height, so the top and
    bottom roundings meet and the side is one curve. edge_radius = edge_bulge
    gives the old round edges on a straight side. The cover's skirt follows
    the top rounding down to mid-height; its inner top edges keep their 2.5 mm
    radius.
2026-10-24 Case: wall rounding 4.5 mm high, so the cover exports as 3MF
    At exactly half the case height (4.55 mm) the cover gets a degenerate
    sliver that the 3MF export in OpenSCAD's current snapshot rejects, which
    failed the STL build. 4.5 leaves a 0.1 mm straight band at mid-height.
2026-10-25 Case: back to round edges on a straight side
    Reverts 837b8a4 and 0c88d70: the wall goes back to quarter-circle
    roundings (edge_radius = edge_bulge = 2.5) at the top and bottom with a
    straight side between, and hump_round follows edge_radius again.
2026-10-26 Case: USB-C opening 0.5 mm higher
    The printed case showed the nano's USB port sitting about 0.5 mm above
    the opening, so usb_below goes from 1.38 to 0.88. The nano cavity and
    the cover height stay as they were.
2026-10-31 Readme: photo of the bare boards
